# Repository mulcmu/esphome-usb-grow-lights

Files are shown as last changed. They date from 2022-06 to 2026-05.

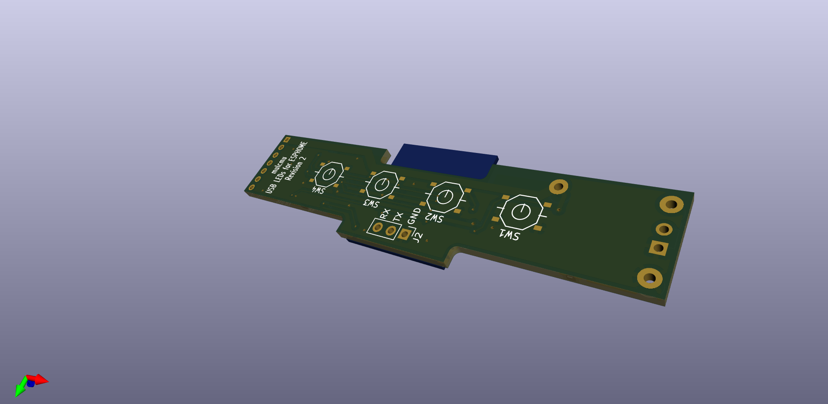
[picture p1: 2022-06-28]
pcb/light_timer back.png

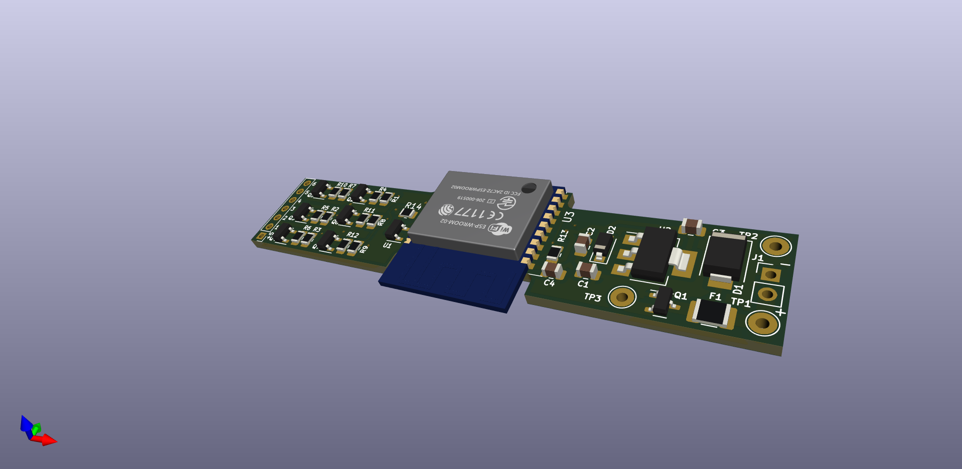
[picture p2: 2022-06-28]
pcb/light_timer.png

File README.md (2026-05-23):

# esphome-usb-grow-lights
Custom PCB to drive usb powered grow lights via ESP8266 and ESPHome.

Project logs posted at https://hackaday.io/project/186050-iot-the-usb-grow-lights.

led_timer_demo.ino simple Arduino sketch to test circuit operation.

basic config.yaml ESPhome is configuration file for control the lights via home assistant and binary sensors for the button states.

Rev2 of the PCB has been tested.  Do not populate the voltage supervisor or get one with a 2.7V threshold level.

The 5V LED bulb drew 900mA at 5V.  Testing a stock control board shows the PWM frequency was 60 Hz with max duty cycle of 15%.  This limits the current from the power supply and doesn't drive the LEDs too hard to prolong lifespan.

TODO:

- ~~Update Rev 2 BOM and post.~~  3.1V supervisor and 2A fuse
- ~~Add ESPHome logic for local control at the light~~
- Design compatible 3d printed case for other generic usb lights

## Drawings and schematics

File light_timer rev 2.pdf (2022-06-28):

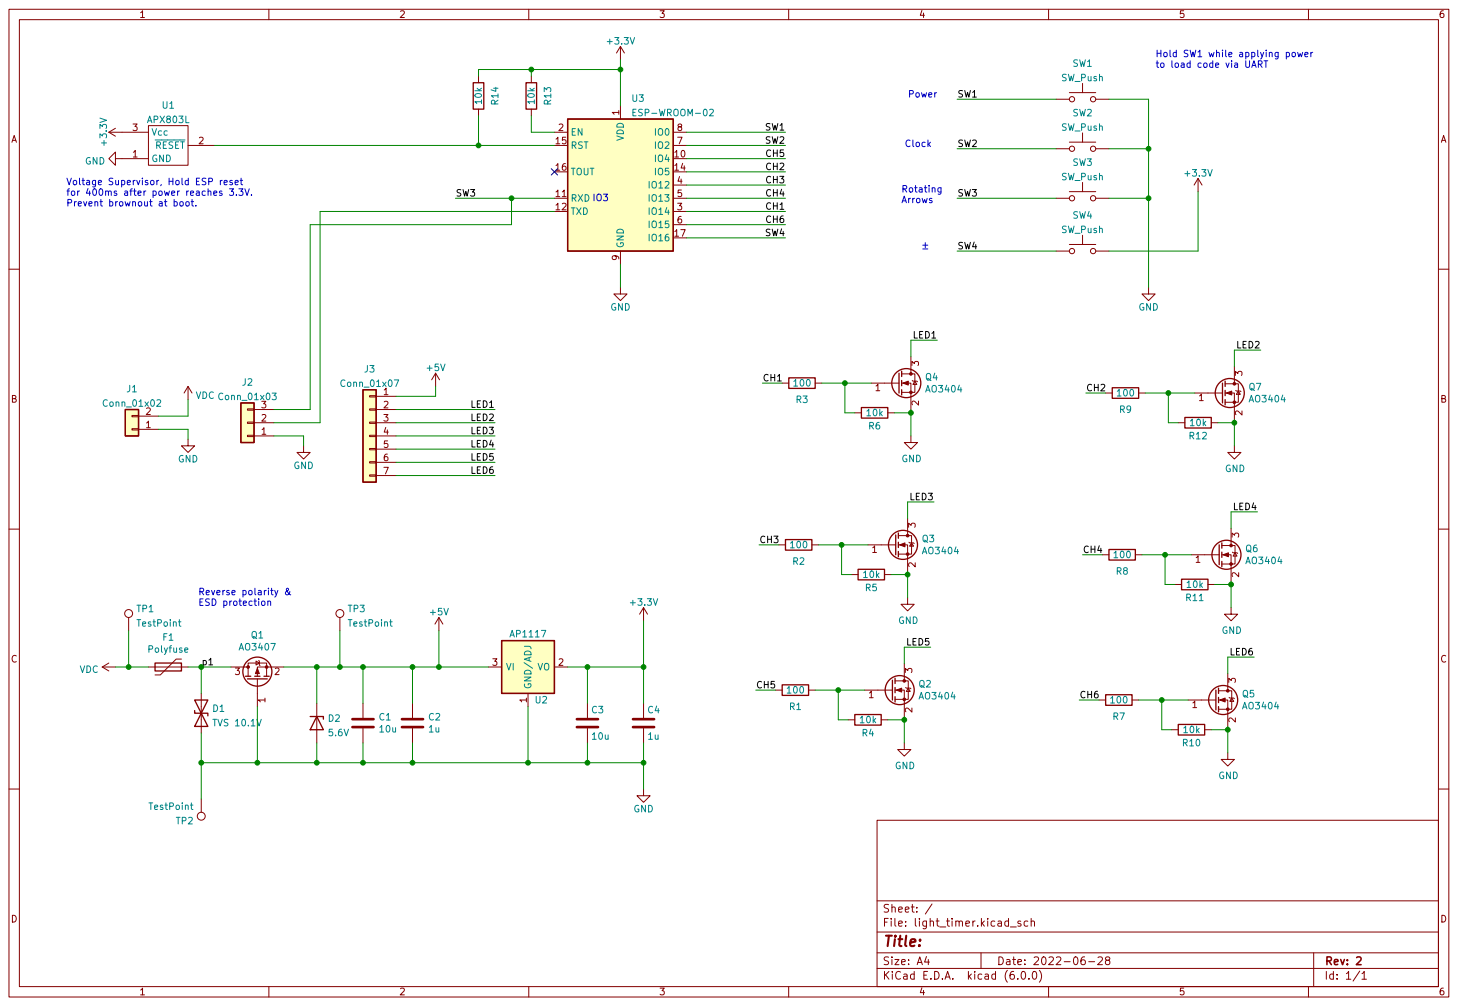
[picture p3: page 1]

to load code via UART

IO3 Voltage Supervisor, Hold ESP reset

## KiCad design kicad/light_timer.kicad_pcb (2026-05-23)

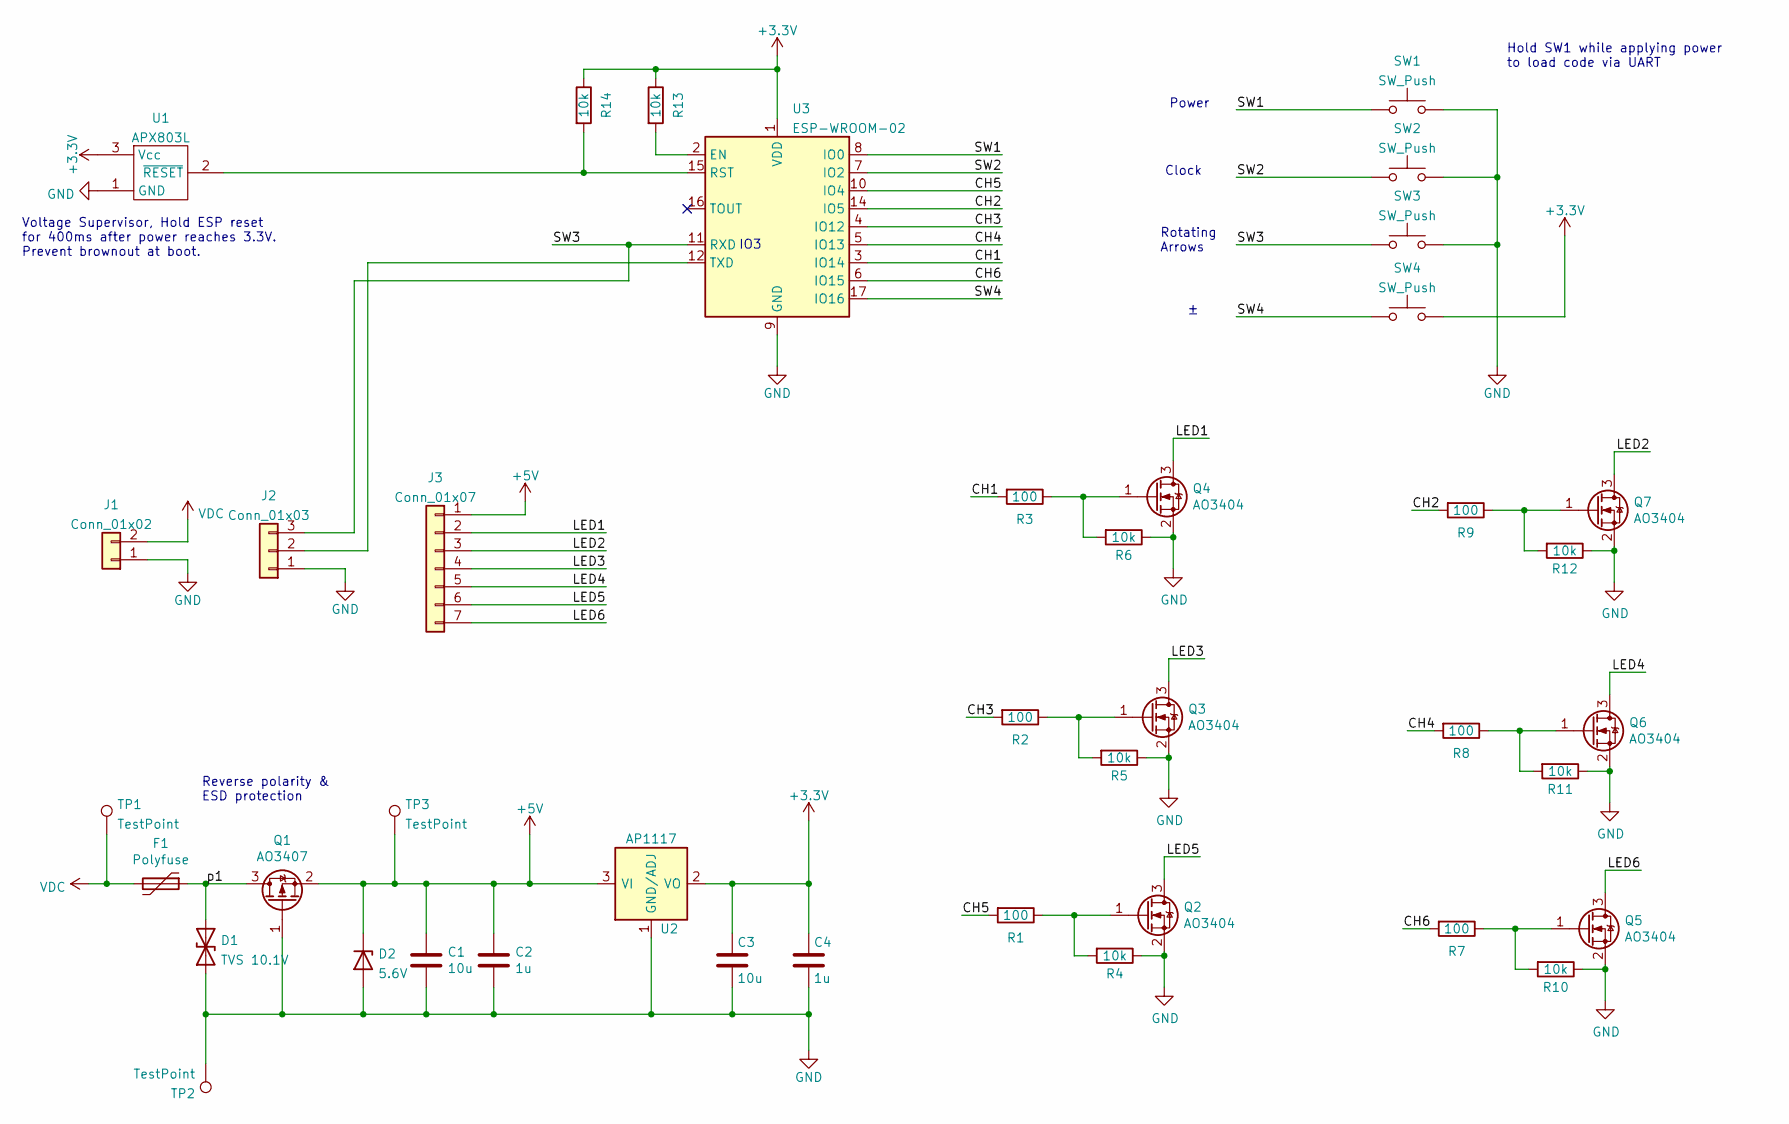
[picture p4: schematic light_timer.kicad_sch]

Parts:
C1, C3: 10u; C_0805_2012Metric
C2, C4: 1u; C_0805_2012Metric
D1: TVS 10.1V; D_SMB
D2: 5.6V; D_SOD-123
F1: Polyfuse; R_1210_3225Metric_Pad1.30x2.65mm_HandSolder
J1: Conn_01x02; PinHeader_1x02_P2.54mm_Vertical
J2: Conn_01x03; PinHeader_1x03_P2.54mm_Vertical
J3: Conn_01x07; PinHeader_1x07_P2.00mm_Vertical
Q1: AO3407; SOT-23
Q2, Q3, Q4, Q5, Q6, Q7: AO3404; SOT-23
R1, R2, R3, R7, R8, R9: 100; R_0805_2012Metric
R4, R5, R6, R10, R11, R12, R13, R14: 10k; R_0805_2012Metric
SW1, SW2, SW3, SW4: SW_Push; 5.2mm button
TP1, TP2, TP3: TestPoint; TestPoint_THTPad_D2.5mm_Drill1.2mm
U1: APX803L; SOT-23
U2: AP1117; SOT-223
U3: ESP-WROOM-02

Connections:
+3V3: C3.1, C4.1, R13.1, R14.1, SW4.2, U1.3 (Vcc), U2.2 (VO), U2.4 (VO), U3.1 (VDD)
+5V: C1.1, C2.1, D2.1 (K), J3.1, Q1.2 (S), TP3.1, U2.3 (VI)
/CH1: R3.2, U3.3 (IO14)
/CH2: R9.2, U3.14 (IO5)
/CH3: R2.2, U3.4 (IO12)
/CH4: R8.2, U3.5 (IO13)
/CH5: R1.2, U3.10 (IO4)
/CH6: R7.2, U3.6 (IO15)
/LED1: J3.2, Q4.3 (D)
/LED2: J3.3, Q7.3 (D)
/LED3: J3.4, Q3.3 (D)
/LED4: J3.5, Q6.3 (D)
/LED5: J3.6, Q2.3 (D)
/LED6: J3.7, Q5.3 (D)
/SW1: SW1.1, U3.8 (IO0)
/SW2: SW2.1, U3.7 (IO2)
/SW3: J2.3, SW3.1, U3.11 (RXD)
/SW4: SW4.1, U3.17 (IO16)
/p1: D1.2 (A2), F1.1, Q1.3 (D)
GND: C1.2, C2.2, C3.2, C4.2, D1.1 (A1), D2.2 (A), J1.1, J2.1, Q1.1 (G), Q2.2 (S), Q3.2 (S), Q4.2 (S), Q5.2 (S), Q6.2 (S), Q7.2 (S), R4.1, R5.1, R6.1, R10.1, R11.1, R12.1, SW1.2, SW2.2, SW3.2, TP2.1, U1.1 (GND), U2.1 (GND/ADJ), U3.9 (GND), U3.13 (GND), U3.18 (GND), U3.19 (GND)
unnamed: J2.2, U3.12 (TXD)
unnamed: Q2.1 (G), R1.1, R4.2
unnamed: Q3.1 (G), R2.1, R5.2
unnamed: Q4.1 (G), R3.1, R6.2
unnamed: Q5.1 (G), R7.1, R10.2
unnamed: Q6.1 (G), R8.1, R11.2
unnamed: Q7.1 (G), R9.1, R12.2
unnamed: R13.2, U3.2 (EN)
unnamed: R14.2, U1.2 (~RESET), U3.15 (RST)
VDC: F1.2, J1.2, TP1.1

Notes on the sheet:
Clock
Reverse polarity & ESD protection
Rotating Arrows
Hold SW1 while applying power to load code via UART
Power
IO3
Voltage Supervisor, Hold ESP reset for 400ms after power reaches 3.3V. Prevent brownout at boot.

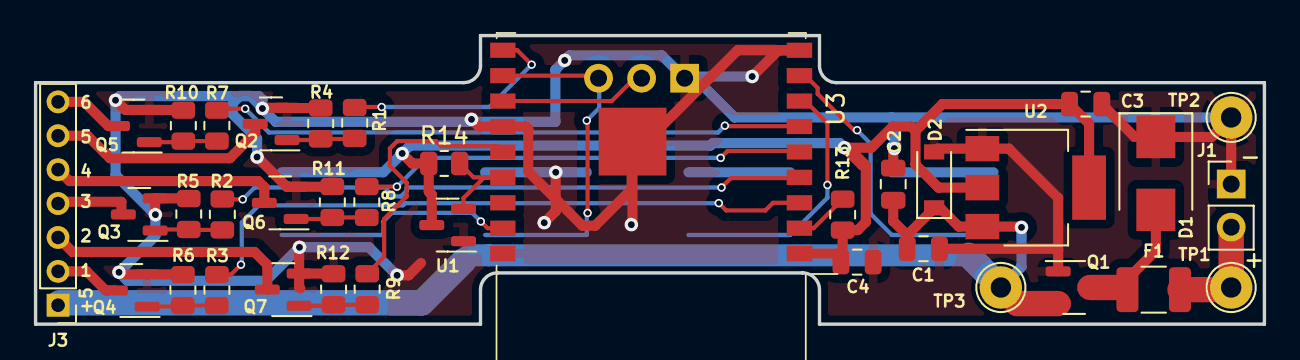
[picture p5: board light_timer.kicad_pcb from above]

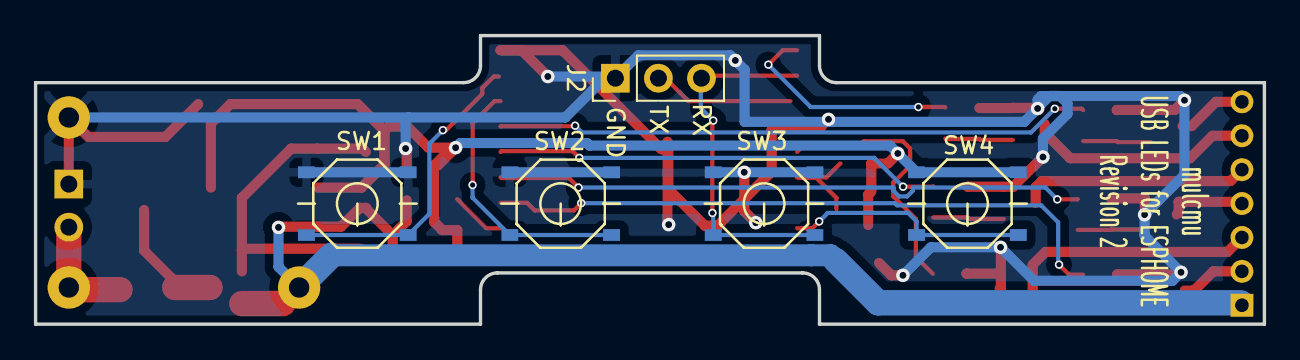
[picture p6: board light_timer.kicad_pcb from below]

Board: 2 copper layers, 72.5 x 17.0 mm, 41 parts (5 on the bottom side), 30 nets.

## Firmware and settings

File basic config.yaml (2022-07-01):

#add a new ESPhome device for generic ESP8266 and add below configuration to
#to the default configuration

#operation of lights and actions from buttons must be implemented in home
#assistant, nothing is automated within the device 
   
#min and max power adjusted to make LED turn on at 1% brightness in HA and 
#not exceed maximum output of the power supply for 100% brightness in HA.
#You may need to tweek this per application
   
output:
  - platform: esp8266_pwm
    pin: 14
    frequency: 1000 Hz
    id: led_pwm_ch1
    min_power: 0.02
    max_power: 0.4
    zero_means_zero: true
  - platform: esp8266_pwm
    pin: 5
    frequency: 1000 Hz
    id: led_pwm_ch2
    min_power: 0.02
    max_power: 0.4
    zero_means_zero: true  
  - platform: esp8266_pwm
    pin: 12
    frequency: 1000 Hz
    id: led_pwm_ch3
    min_power: 0.02
    max_power: 0.4
    zero_means_zero: true 
  - platform: esp8266_pwm
    pin: 13
    frequency: 1000 Hz
    id: led_pwm_ch4
    min_power: 0.02
    max_power: 0.4
    zero_means_zero: true  
  - platform: esp8266_pwm
    pin: 4
    frequency: 1000 Hz
    id: led_pwm_ch5
    min_power: 0.02
    max_power: 0.4
    zero_means_zero: true  
  - platform: esp8266_pwm
    pin: 15
    frequency: 1000 Hz
    id: led_pwm_ch6 
    min_power: 0.02
    max_power: 0.4
    zero_means_zero: true 

light:
  - platform: monochromatic
    output: led_pwm_ch1
    name: "LED CH1 Light"  
  - platform: monochromatic
    output: led_pwm_ch2
    name: "LED CH2 Light"      
  - platform: monochromatic
    output: led_pwm_ch3
    name: "LED CH3 Light"  
  - platform: monochromatic
    output: led_pwm_ch4
    name: "LED CH4 Light"  
  - platform: monochromatic
    output: led_pwm_ch5
    name: "LED CH5 Light"  
  - platform: monochromatic
    output: led_pwm_ch6
    name: "LED CH6 Light"      
    
sensor:
  # Uptime sensor.
  - platform: uptime
    name: led_pwm Uptime

  # WiFi Signal sensor.
  - platform: wifi_signal
    name: led_pwm WiFi Signal
    update_interval: 60s


binary_sensor:
  - platform: gpio
    name: "Power Button"
    pin:
      number: 0
      inverted: true
      mode:
        input: true
        pullup: true
    filters:
      - delayed_on: 3ms
      - delayed_off: 3ms        
  - platform: gpio
    name: "Clock Button"
    pin:
      number: 2
      inverted: true
      mode:
        input: true
        pullup: true
    filters:
      - delayed_on: 3ms
      - delayed_off: 3ms        
  - platform: gpio
    name: "Cycle Button"
    pin:
      number: 3
      inverted: true
      mode:
        input: true
        pullup: true
    filters:
      - delayed_on: 3ms
      - delayed_off: 3ms        
  - platform: gpio
    name: "Brightness Button"
    pin:
      number: 16
      inverted: false
      mode:
        input: true
        pulldown: true   
    filters:
      - delayed_on: 3ms
      - delayed_off: 3ms        

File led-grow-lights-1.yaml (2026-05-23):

esphome:
  name: led-grow-lights-1

esp8266:
  board: esp01_1m

# Enable logging
logger:

# Enable Home Assistant API
api:
  encryption:
    key: 

ota:
  password: 
  platform: esphome
  
wifi:
  ssid: !secret wifi_ssid
  password: !secret wifi_password

  # Enable fallback hotspot (captive portal) in case wifi connection fails
  ap:
    ssid: "Led-Grow-Lights-1"
    password: "xrtJOk6BfJM4"

captive_portal:
    
output:
  - platform: esp8266_pwm
    pin: 5
    frequency: 1000 Hz
    id: led_pwm_ch2
    min_power: 0.02
    max_power: 0.4
    zero_means_zero: true  
  - platform: esp8266_pwm
    pin: 13
    frequency: 1000 Hz
    id: led_pwm_ch4
    min_power: 0.02
    max_power: 0.4
    zero_means_zero: true  

light:
  - platform: monochromatic
    output: led_pwm_ch2
    name: "Left Arm"      
    id: left_arm
  - platform: monochromatic
    output: led_pwm_ch4
    name: "Right Arm"  
    id: right_arm
    
sensor:
  # Uptime sensor.
  - platform: uptime
    name: led_pwm Uptime

  # WiFi Signal sensor.
  - platform: wifi_signal
    name: led_pwm WiFi Signal
    update_interval: 60s


binary_sensor:
  - platform: gpio
    name: "Power Button"
    pin:
      number: 0
      inverted: true
      mode:
        input: true
        pullup: true
    filters:
      - delayed_on: 3ms
      - delayed_off: 3ms
    on_press:
      then:
        - lambda: !lambda |-
            bool left_on = false;
            bool right_on = false;
            id(left_arm).current_values_as_binary(&left_on);
            id(right_arm).current_values_as_binary(&right_on);
            ESP_LOGD("main", "Power button press:  %d : %d", left_on, right_on);
            if (left_on || right_on) {
              id(left_arm).turn_off().perform();
              id(right_arm).turn_off().perform();
              ESP_LOGD("main", "  Off Branch");
            }
            else {
              if(id(light_mode).current_option() == std::string("Both")) {
                id(left_arm).turn_on().perform();
                id(right_arm).turn_on().perform();
                ESP_LOGD("main", "  Both Branch");                
              }
              if(id(light_mode).current_option()==std::string("Left")) {
                id(left_arm).turn_on().perform();
                id(right_arm).turn_off().perform();
                ESP_LOGD("main", "  Left Branch");                
              }
              if(id(light_mode).current_option()==std::string("Right")) {
                id(left_arm).turn_off().perform();
                id(right_arm).turn_on().perform();
                ESP_LOGD("main", "  Right Branch");
              }
            }
  - platform: gpio
    name: "Clock Button"
    pin:
      number: 2
      inverted: true
      mode:
        input: true
        pullup: true
    filters:
      - delayed_on: 3ms
      - delayed_off: 3ms 
    on_press:
      then:
        - lambda: !lambda |-
            ESP_LOGD("main", "Clock button press:");

  - platform: gpio
    name: "Cycle Button"
    pin:
      number: 3
      inverted: true
      mode:
        input: true
        pullup: true
    filters:
      - delayed_on: 3ms
      - delayed_off: 3ms  
    on_press:
      then:
        - lambda: !lambda |-
            ESP_LOGD("main", "Cycle button press:");
        - select.next: light_mode


  - platform: gpio
    name: "Brightness Button"
    pin:
      number: 16
      inverted: false
      mode:
        input: true
        pulldown: true   
    filters:
      - delayed_on: 3ms
      - delayed_off: 3ms 
    on_press:
      then:
        - lambda: !lambda |-
            ESP_LOGD("main", "Brightness button press:");
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

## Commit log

2022-06-28 PCB Rev 2
2026-05-23 kicad upload
    [light_timer.kicad_pcb, light_timer.kicad_sch]
